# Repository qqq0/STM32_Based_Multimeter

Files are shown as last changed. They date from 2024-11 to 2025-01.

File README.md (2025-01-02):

# **STM32 BLE Multimeter**

**Multimeter features:**
- USB rechargeable LiPo battery  
- BLE control and data streaming  
- Auto range detection  
- Optional OLED display/button control  

**Measurement types:**
- DC voltage: 0 - 60V  
- DC current: 0 - 10A (5 sec)  
- DC power: 0 - 600 W (5 sec)  
- Resistance: 1 - 1M ohm  
- Inductance  
- Capacitance (non-polarized)  
- Diode: 3.3V  

**PCB FRONT:**

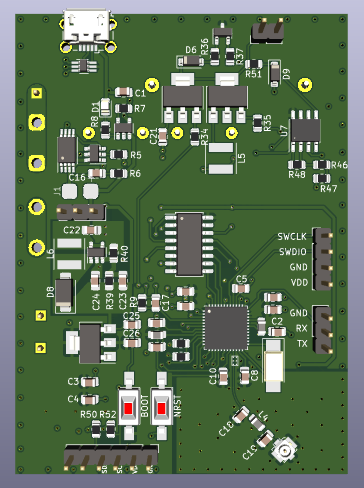
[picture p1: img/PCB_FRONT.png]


**PCB BACK:**

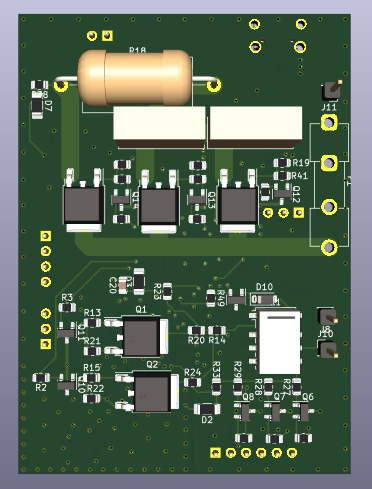
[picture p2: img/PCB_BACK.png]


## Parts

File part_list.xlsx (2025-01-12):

# | Reference | Qty | Value | Shop link | Footprint | order Qty | Price PLN | Total Price | shiping | Kolumna1
1 | C1, C2, C3, C4, C11, C22, C24 | 7 | 4,7 uF | mam 12 https://pl.aliexpress.com/item/1005006285113165.html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 | Capacitor_SMD:C_0805_2012Metric | 1 | 1.69 zł | 6.77 zł | 5.08
2 | C5, C6, C7, C8, C9, C10, C12, C13, C16, C17, C20 | 11 | 100 nF | mam 6 == | Capacitor_SMD:C_0805_2012Metric | 1 | 2.10 zł | 2.10 zł | 0
3 | C18, C19 | 2 | NF |  | Capacitor_SMD:C_0805_2012Metric | 0 |  | 0.00 zł
4 | C21 | 1 | 1uF |  | Capacitor_SMD:C_0805_2012Metric | 0 |  | 0.00 zł
5 | C23 | 1 | 22pF |  | Capacitor_SMD:C_0805_2012Metric_Pad1.18x1.45mm_HandSolder | 0 |  | 0.00 zł
6 | C25, C26 | 2 | 10 uF |  | Capacitor_SMD:C_0805_2012Metric | 0 |  | 0.00 zł
7 | D1 | 1 | LED |  | LED_SMD:LED_0805_2012Metric | 0 |  | 0.00 zł
8 | D2, D3, D7 | 3 | 3V3 D_Zener | https://pl.aliexpress.com/item/1005008305688305.html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 | Resistor_SMD:R_1206_3216Metric_Pad1.30x1.75mm_HandSolder | 1 | 3.79 zł | 8.02 zł | 4.23
9 | D4, D5 | 2 | Z0103MN | https://pl.aliexpress.com/item/1005003648689674.html?pdp_ext_f=%7B"order"%3A"14"%2C"eval"%3A"1"%7D&pdp_npi=4%40dis%21PLN%212.31%212.30%21%21%210.54%210.54%21%402103985c17359917700825783e6386%2112000026643663160%21sea%21PL%212234627410%21X&curPageLogUid=U1r9Vrj7ugJC&utparam-url=scene%3Asearch%7Cquery_from%3A | Package_TO_SOT_SMD:SOT-223 | 1 | 2.39 zł | 7.00 zł | 4.61
10 | D6, D9, D10, D8 | 4 | 1N4148W | - | Diode_SMD:D_SOD-123 | 0 |  | 0.00 zł
11 | F1 | 1 | 10A Fuse | https://pl.aliexpress.com/item/1005003009277399.html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 https://pl.aliexpress.com/item/1005007482886989.html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 | Fuse:Fuseholder_Clip-5x20mm_Eaton_1A5601-01_Inline_P20.80x6.76mm_D1.70mm_Horizontal | 1 | 7.64 zł | 18.64 zł | 11
12 | J1 | 1 | Conn_01x02_Pin | Solder directly to PCB | moje_elementy:batt | 0 |  | 0.00 zł
13 | J2 | 1 | USB_B_Micro | https://pl.aliexpress.com/item/1005006331276552.html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 | Connector_USB:USB_Micro-B_Wuerth_629105150521_CircularHoles | 1 | 1.69 zł | 6.45 zł | 4.76
14 | J3 | 1 | Conn_01x04_Pin |  | Connector_PinHeader_2.54mm:PinHeader_1x04_P2.54mm_Vertical | 0 |  | 0.00 zł
15 | J4 | 1 | Conn_Coaxial | https://pl.aliexpress.com/item/1005005845330862.html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 | Connector_Coaxial:U.FL_Molex_MCRF_73412-0110_Vertical | 1 | 1.99 zł | 7.62 zł | 5.63
16 | J5 | 1 | Conn_01x03_Pin |  | Connector_PinHeader_2.54mm:PinHeader_1x03_P2.54mm_Vertical | 0 |  | 0.00 zł
17 | J7 | 1 | Conn_01x02_Pin |  | Connector_PinHeader_2.54mm:PinHeader_1x02_P2.54mm_Vertical | 0 |  | 0.00 zł
18 | J8, J10, J11 | 3 | Conn_01x01_Pin |  | Connector_PinHeader_2.54mm:PinHeader_1x01_P2.54mm_Vertical | 0 |  | 0.00 zł
19 | J9 | 1 | Conn_01x06_Pin |  | Connector_PinHeader_2.54mm:PinHeader_1x06_P2.54mm_Vertical | 0 |  | 0.00 zł
20 | K1 | 1 | G6K-2 | https://pl.aliexpress.com/item/1005007294651555.html?scm_id=1007.40196.366991.0&scm-url=1007.40196.366991.0 | Relay_SMD:Relay_DPDT_Omron_G6K-2F-Y 3VDC | 1 | 11.13 zł | 17.06 zł | 5.93
21 | L1,L2 | 2 | 10 uH | https://pl.aliexpress.com/item/32955754327.html?pdp_ext_f=%7B"order"%3A"52"%2C"eval"%3A"1"%7D&pdp_npi=4%40dis%21PLN%212.35%212.35%21%21%210.55%210.55%21%40211b81a317359922338361382e774b%2166332555126%21sea%21PL%212234627410%21X&curPageLogUid=cJKDvUjTB2LD&utparam-url=scene%3Asearch%7Cquery_from%3A | Inductor_SMD:L_0805_2012Metric | 1 | 2.35 zł | 7.39 zł | 5.04
22
23 | L4 | 1 | 0H | set | Inductor_SMD:L_0805_2012Metric | 0 |  | 0.00 zł
24 | L5, L6 | 2 | 10uH | https://pl.aliexpress.com/item/1005002090028747.html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 | Inductor_SMD:L_Taiyo-Yuden_NR-50xx | 1 | 2.13 zł | 6.95 zł | 4.82
25 | Q1, Q2, Q3, Q4, Q5 | 5 | AOD2810 | https://pl.aliexpress.com/item/1005005809146268.html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 | moje_elementy:TO-252-1 | 1 | 7.01 zł | 11.04 zł | 4.03
26 | Q6, Q7, Q8, Q9, Q10, Q11, Q12, Q13, Q14, Q15 | 10 | BC327 | Zmienić na PCB coś SOT-23 | Package_TO_SOT_SMD:SOT-23-3 |  |  | 0.00 zł
27 | R2, R3, R4, R30, R31, R32, R34, R35, R37, R43, R45, R49 | 12 | 2k2 R | set | Resistor_SMD:R_0805_2012Metric | 0 |  | 0.00 zł
28 | R5, R8, R13, R15, R28, R41, R42, R44 | 8 | 1k R | set | Resistor_SMD:R_0805_2012Metric | 0 |  | 0.00 zł
29 | R6 | 1 | 100R | set | Resistor_SMD:R_0805_2012Metric | 0 |  | 0.00 zł
30 | R7, R9, R50, R52 | 4 | 2k R | set | Resistor_SMD:R_0805_2012Metric | 0 |  | 0.00 zł
31 | R11, R12 | 2 | 511k R | set | Resistor_SMD:R_0805_2012Metric | 0 |  | 0.00 zł
32 | R14 | 1 | 900k R | set | Resistor_SMD:R_0805_2012Metric | 0 |  | 0.00 zł
33 | R16 | 1 | 0,01 R | https://pl.aliexpress.com/item/1005005181109774.html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 | Resistor_THT:R_Box_L14.0mm_W5.0mm_P9.00mm | 1 | 1.99 zł | 6.81 zł | 4.82
34 | R17 | 1 | 0,1 R | https://pl.aliexpress.com/item/1005005181109774.html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 | Resistor_THT:R_Box_L14.0mm_W5.0mm_P9.00mm | 1 | 1.99 zł | 1.99 zł
35 | R18 | 1 | 1 R |  | Resistor_THT:R_Axial_DIN0918_L18.0mm_D9.0mm_P25.40mm_Horizontal | 0 |  | 0.00 zł
36 | R19, R20, R21, R22, R23, R25, R26, R29, R33, R38, R51 | 11 | 100k R | https://pl.aliexpress.com/item/1005007636030489.html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 | Resistor_SMD:R_0805_2012Metric | 1 | 13.19 zł | 13.19 zł |  | 80value 2000 pcs
37 | R24 | 1 | 9,1k R | set | Resistor_SMD:R_0805_2012Metric | 0 |  | 0.00 zł
38 | R27 | 1 | 100 R | set | Resistor_SMD:R_0805_2012Metric | 0 |  | 0.00 zł
39 | R36 | 1 | 220 R | set | Resistor_SMD:R_0805_2012Metric | 0 |  | 0.00 zł
40 | R39 | 1 | 470k R | set | Resistor_SMD:R_0805_2012Metric_Pad1.20x1.40mm_HandSolder | 0 |  | 0.00 zł
41 | R40 | 1 | 75k R | set | Resistor_SMD:R_0805_2012Metric_Pad1.20x1.40mm_HandSolder | 0 |  | 0.00 zł
42 | R46 | 1 | 43k R | set | Resistor_SMD:R_0805_2012Metric | 0 |  | 0.00 zł
43 | R47 | 1 | 330 R | set | Resistor_SMD:R_0805_2012Metric | 0 |  | 0.00 zł
44 | R48 | 1 | 390k R | set | Resistor_SMD:R_0805_2012Metric | 0 |  | 0.00 zł
45 | SW1 | 1 | NRST |  | Button_Switch_SMD:SW_SPST_FSMSM | 0 |  | 0.00 zł
46 | SW3 | 1 | BOOT |  | Button_Switch_SMD:SW_SPST_FSMSM | 0 |  | 0.00 zł
47 | SW4 | 1 | SW_DPDT_x2 |  | Connector_PinHeader_2.54mm:PinHeader_1x03_P2.54mm_Vertical | 0 |  | 0.00 zł
48 | U1 | 1 | STM32WB55CGUx | https://pl.aliexpress.com/item/1005008038998896.html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 | Package_DFN_QFN:QFN-48-1EP_7x7mm_P0.5mm_EP5.6x5.6mm | 2 | 13.59 zł | 31.71 zł | 4.53
49 | U3 | 1 | LTC4054XES5-4.2 | https://pl.aliexpress.com/item/1005006928245080.html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 | Package_TO_SOT_SMD:TSOT-23-5 | 1 | 2.17 zł | 6.74 zł | 4.57
50 | U4 | 1 | DW01A | https://pl.aliexpress.com/item/1005007467171055.html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 | Package_TO_SOT_SMD:SOT-23-6 | 1 | 4.79 zł | 9.32 zł | 4.53
51 | U5 | 1 | FS8205A | set | Package_SO:TSSOP-8_4.4x3mm_P0.65mm | 0 |  | 0.00 zł
52 | U6 | 1 | ~ | https://pl.aliexpress.com/item/1005007978414767.html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 | Package_TO_SOT_SMD:SOT-363_SC-70-6_Handsoldering | 1 | 2.25 zł | 6.32 zł | 4.07
53 | U7 | 1 | MCP602 | https://pl.aliexpress.com/item/1005006922903852.html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 | Package_SO:SOP-8_3.9x4.9mm_P1.27mm | 1 | 4.20 zł | 4.20 zł | 0
54 | U8 | 1 | ~ | https://pl.aliexpress.com/item/1005006779802761.html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 | moje_elementy:MLPF-WB55 | 2 | 4.69 zł | 13.08 zł | 3.7
55 | U9 | 1 | TPS61040DBV |  | Package_TO_SOT_SMD:SOT-23-5 | 0 |  | 0.00 zł
56 | U10 | 1 | AMS1117-3.3 |  | Package_TO_SOT_SMD:SOT-223-3_TabPin2 | 0 |  | 0.00 zł
57 | U11 | 1 | 4051 | https://pl.aliexpress.com/item/1005007329677951.html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 | Package_SO:SOP-16_4.4x10.4mm_P1.27mm | 1 | 3.20 zł | 6.79 zł | 3.59
58 | Y1 | 1 | Crystal 32 MHz | https://pl.aliexpress.com/item/1005006142975427.html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 | Crystal:Crystal_SMD_5032-2Pin_5.0x3.2mm_HandSoldering | 1 | 4.20 zł | 4.20 zł
59 |  | 1 | Antena | https://pl.aliexpress.com/item/1005006057629673.html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 | 2.4G Bluetooth wifi mała antena 5G 5.8G UFL | 1 | 6.69 zł | 6.69 zł | 0
60 |  |  |  |  |  |  |  | 0.00 zł
61 |  |  |  |  |  |  |  | 0.00 zł
 |  |  |  |  |  | suma | 210.08 zł

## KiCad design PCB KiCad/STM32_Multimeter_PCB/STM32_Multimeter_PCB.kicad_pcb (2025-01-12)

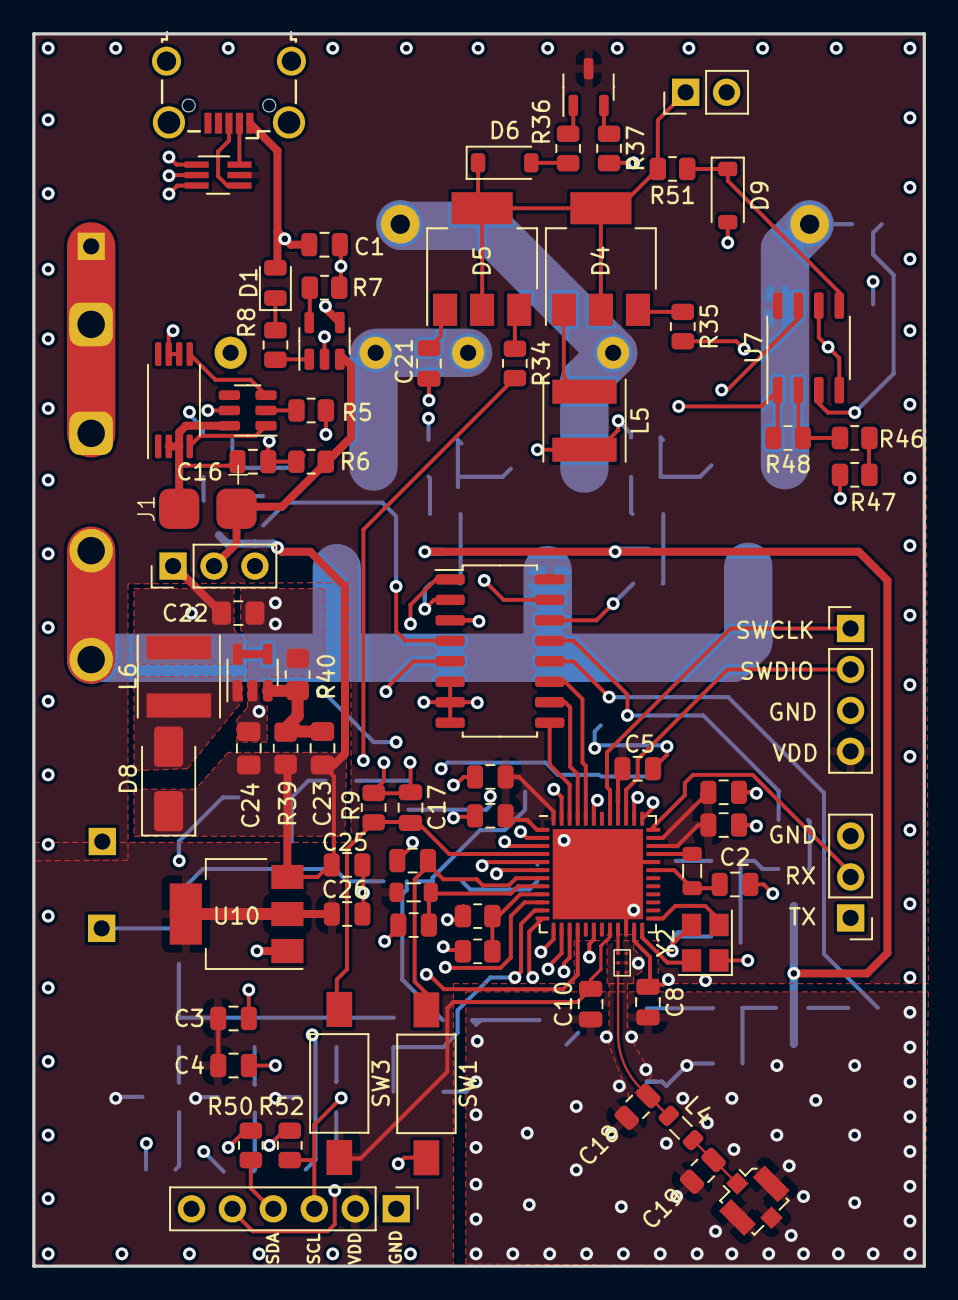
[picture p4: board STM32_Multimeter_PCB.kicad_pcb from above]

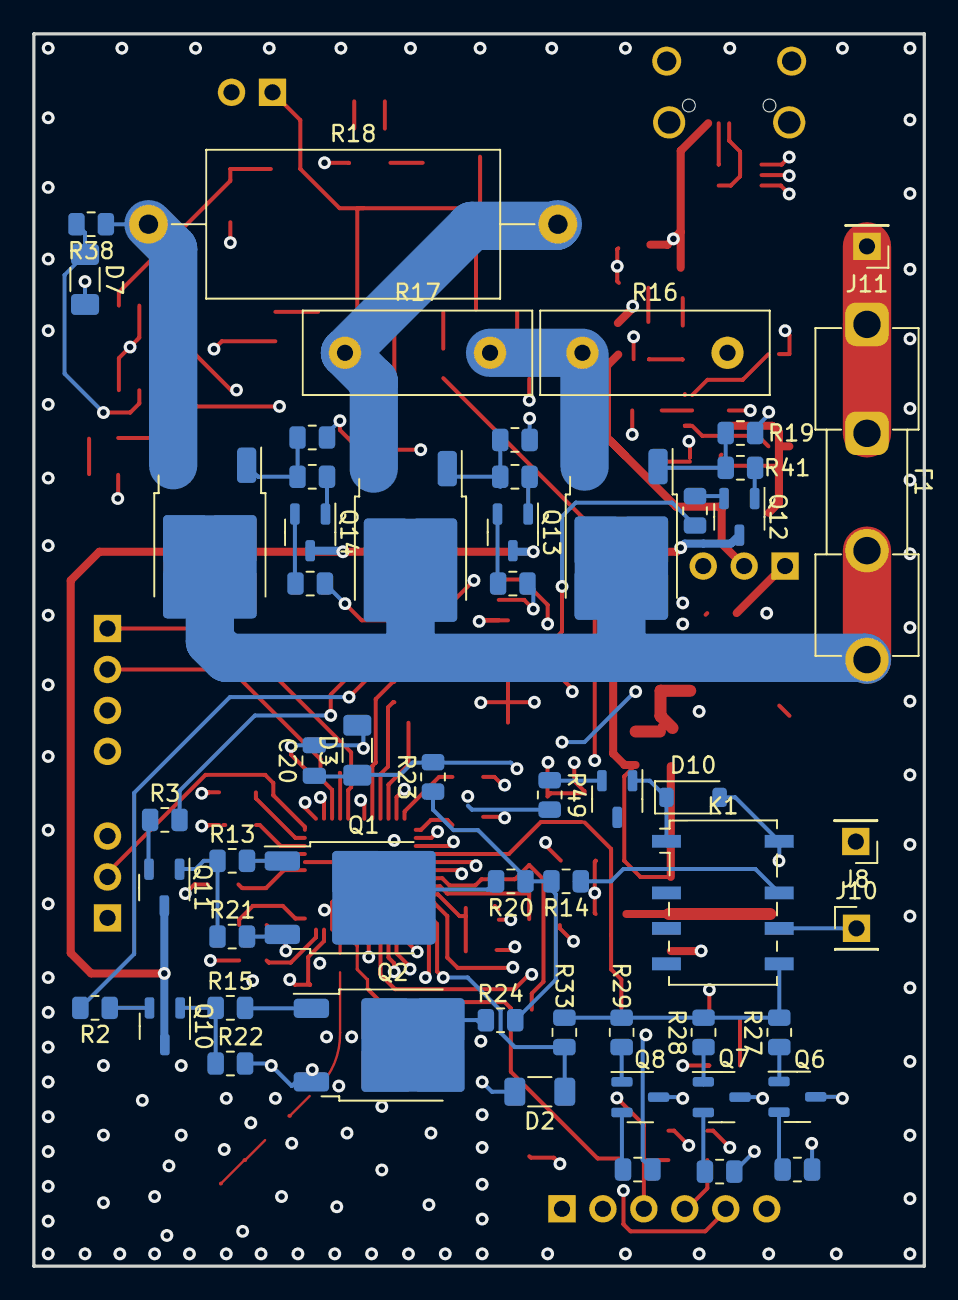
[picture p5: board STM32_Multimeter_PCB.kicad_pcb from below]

Board: 4 copper layers, 55.2 x 76.5 mm, 130 parts (55 on the bottom side), 105 nets.

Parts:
C1, C2, C3, C4, C11: 4,7 uF; C_0805_2012Metric
C5, C6, C7, C8, C9, C10, C12, C13, C16, C17, C20: 100 nF; C_0805_2012Metric
C18, C19: NF; C_0805_2012Metric
C21: 1uF; C_0805_2012Metric
C22, C24: 4.7uF; C_0805_2012Metric_Pad1.18x1.45mm_HandSolder
C23: 22pF; C_0805_2012Metric_Pad1.18x1.45mm_HandSolder
C25, C26: 10 uF; C_0805_2012Metric
D1: LED; LED_0805_2012Metric
D2, D3, D7: 3V3 D_Zener; R_1206_3216Metric_Pad1.30x1.75mm_HandSolder
D4, D5: Z0103MN; SOT-223
D6, D9, D10: 1N4148W; D_SOD-123
D8: 1N4001; D_SMA
F1: 10A Fuse; Fuseholder_Clip-5x20mm_Eaton_1A5601-01_Inline_P20.80x6.76mm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
J1: Conn_01x02_Pin; batt
J2: USB_B_Micro; USB_Micro-B_Wuerth_629105150521_CircularHoles
J3: Conn_01x04_Pin; PinHeader_1x04_P2.54mm_Vertical
J4: Conn_Coaxial; U.FL_Molex_MCRF_73412-0110_Vertical
J5: Conn_01x03_Pin; PinHeader_1x03_P2.54mm_Vertical
J7: Conn_01x02_Pin; PinHeader_1x02_P2.54mm_Vertical
J8, J10, J11: Conn_01x01_Pin; PinHeader_1x01_P2.54mm_Vertical
J9: Conn_01x06_Pin; PinHeader_1x06_P2.54mm_Vertical
K1: G6K-2; Relay_DPDT_Omron_G6K-2F-Y
L1, L2: 10 uH; L_0805_2012Metric
L4: 0H; L_0805_2012Metric
L5, L6: 10uH; L_Taiyo-Yuden_NR-50xx
Q1, Q2, Q3, Q4, Q5: AOD2810; TO-252-1
Q6, Q7, Q8, Q9, Q10, Q11, Q12, Q13, Q14, Q15: BC327; SOT-23-3
R2, R3, R4, R30, R31, R32, R34, R35, R37, R43, R45, R49: 2k2 R; R_0805_2012Metric
R5, R8, R13, R15, R28, R41, R42, R44: 1k R; R_0805_2012Metric
R6: 100R; R_0805_2012Metric
R7, R9, R50, R52: 2k R; R_0805_2012Metric
R11, R12: 511k R; R_0805_2012Metric
R14: 910k R; R_0805_2012Metric
R16: 0,01 R; R_Box_L14.0mm_W5.0mm_P9.00mm
R17: 0,1 R; R_Box_L14.0mm_W5.0mm_P9.00mm
R18: 1 R; R_Axial_DIN0918_L18.0mm_D9.0mm_P25.40mm_Horizontal
R19, R20, R21, R22, R23, R25, R26, R29, R33, R38, R51: 100k R; R_0805_2012Metric
R24: 9,1k R; R_0805_2012Metric
R27: 100 R; R_0805_2012Metric
R36: 220 R; R_0805_2012Metric
R39: 470k R; R_0805_2012Metric_Pad1.20x1.40mm_HandSolder
R40: 75k R; R_0805_2012Metric_Pad1.20x1.40mm_HandSolder
R46: 43k R; R_0805_2012Metric
R47: 330 R; R_0805_2012Metric
R48: 390k R; R_0805_2012Metric
SW1: NRST; SW_SPST_FSMSM
SW3: BOOT; SW_SPST_FSMSM
SW4: SW_DPDT_x2; PinHeader_1x03_P2.54mm_Vertical
U1: STM32WB55CGUx; QFN-48-1EP_7x7mm_P0.5mm_EP5.6x5.6mm
U3: LTC4054XES5-4.2; TSOT-23-5
U4: DW01A; SOT-23-6
U5: FS8205A; TSSOP-8_4.4x3mm_P0.65mm
U6: SOT-363_SC-70-6_Handsoldering
U7: SOP-8_3.9x4.9mm_P1.27mm
U8: MLPF-WB55
U9: TPS61040DBV; SOT-23-5
U10: AMS1117-3.3; SOT-223-3_TabPin2
U11: 4051; SOP-16_4.4x10.4mm_P1.27mm
Y2: Crystal_GND24; Crystal_SMD_3225-4Pin_3.2x2.5mm

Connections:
+5V: C1.2, D1.2 (A), J2.1 (VBUS), U3.4 (V_{CC})
+9V: C23.1, C24.1, C25.2, D8.1 (K), Q10.3 (E), Q11.3 (E), Q12.3 (E), Q13.3 (E), Q14.3 (E), R39.1, U10.3 (VI)
+BATT: C22.1, L6.1, R11.2, SW4.1 (A), U9.4 (EN), U9.5 (VIN)
A: U1.44 (PB4), U11.11 (A)
B: U1.45 (PB5), U11.10 (B)
BATT sens: R11.1, R12.2, U1.9 (PA0)
BU1: J9.6, U1.2 (PC14)
BU2: J9.5, U1.3 (PC15)
C: U1.46 (PB6), U11.9 (C)
C on: R34.2, U1.16 (PA7)
CL input: U1.14 (PA5), U7.7 (Voutb)
GND: C1.1, C2.2, C3.1, C4.1, C5.1, C6.1, C7.1, C8.2, C9.2, C10.1, C11.1, C12.1, C13.1, C17.1, C18.2, C19.2, C20.2, C21.2, C22.2, C24.2, C25.1, C26.1, D2.2 (A), D3.2 (A), D7.2 (A), D9.2 (A), D10.2 (A), J2.5 (GND), J2.6 (Shield), J3.3, J4.2 (Ext), J5.3, J7.2, J8.1, J9.1, K1.8, L5.2, Q1.3 (S), Q2.3 (S), R5.1, R7.1, R9.1, R12.1, R16.2, R19.2, R21.2, R22.2, R25.2, R26.2, R40.2, R46.1, R50.1, R52.1, SW1.2, U1.22 (VSSRF), U1.32 (VSSSMPS), U1.49 (VSS), U3.2 (GND), U5.6 (S2), U5.7 (S2), U6.2 (GND), U7.4 (Vss), U7.6 (Vinb-), U8.2 (GND_4), U8.4 (GND_3), U8.5 (GND_2), U8.6 (GND_1), U9.2 (GND), U10.1 (GND), U11.6 (Inh), U11.7 (VEE), U11.8 (VSS), Y2.1, Y2.3
L on: R35.2, U1.15 (PA6)
unnamed: D1.1 (K), R8.2
unnamed: D4.1 (A1), L5.1
unnamed: D4.2 (A2), D4.4 (A4), D5.2 (A2), D5.4 (A4), D6.1 (K), J7.1, R51.2
unnamed: D4.3 (G), R35.1
unnamed: C21.1, D5.1 (A1)
unnamed: D5.3 (G), R34.1
unnamed: D6.2 (A), R36.1
unnamed: D7.1 (K), R38.2, U7.3 (Vina+)
unnamed: D8.2 (A), L6.2, U9.1 (SW)
unnamed: D9.1 (K), R51.1, U7.5 (Vinb+)
unnamed: D10.1 (K), K1.1, Q15.1 (C)
unnamed: C16.1, J1.1, U4.6 (GND), U5.2 (S1), U5.3 (S1)
unnamed: J1.2, R6.2, SW4.2 (B), U3.3 (BAT)
unnamed: J2.3 (D+), U6.4 (D4)
unnamed: J2.2 (D-), U6.6 (D3)
unnamed: J3.1, U1.41 (PA14)
unnamed: J3.2, U1.39 (PA13)
unnamed: C19.1, J4.1 (In), L4.2
unnamed: J5.1, U1.18 (PA9)
unnamed: J5.2, U1.36 (PA10)
unnamed: J9.3, R52.2, U1.5 (PB8)
unnamed: J9.4, R50.2, U1.6 (PB9)
unnamed: J10.1, K1.6
unnamed: F1.1, J11.1
unnamed: K1.5, R27.2, R28.2, R29.2, R33.1
unnamed: K1.7, R14.1
unnamed: Q1.1 (D), R20.2
unnamed: Q1.2 (G), R13.2
unnamed: Q2.1 (D), R24.1
unnamed: Q2.2 (G), R15.2
unnamed: F1.2, Q3.1 (D), Q4.1 (D), Q5.1 (D)
unnamed: Q3.2 (G), R19.1, R41.1
unnamed: Q3.3 (S), R16.1, R17.2
unnamed: Q4.2 (G), R25.1, R42.1
unnamed: Q4.3 (S), R17.1, R18.2
unnamed: Q5.2 (G), R26.1, R44.1
unnamed: Q5.3 (S), R18.1, R38.1
unnamed: Q6.2 (B), R30.2
unnamed: Q6.1 (C), R27.1
unnamed: Q7.2 (B), R31.2
unnamed: Q7.1 (C), R28.1
unnamed: Q8.2 (B), R32.2
unnamed: Q8.1 (C), R29.1
unnamed: Q9.2 (B), R37.1
unnamed: Q9.1 (C), R36.2
unnamed: Q10.2 (B), R2.1
unnamed: Q10.1 (C), R15.1, R22.1
unnamed: Q11.2 (B), R3.1
unnamed: Q11.1 (C), R13.1, R21.1
unnamed: Q12.2 (B), R4.1
unnamed: Q12.1 (C), R41.2
unnamed: Q13.2 (B), R43.1
unnamed: Q13.1 (C), R42.2
unnamed: Q14.2 (B), R45.1
unnamed: Q14.1 (C), R44.2
unnamed: Q15.2 (B), R49.1
unnamed: R14.2, R20.1, R23.1, R24.2
unnamed: R46.2, R47.1
unnamed: C12.2, SW1.1, U1.7 (NRST)
unnamed: U1.25 (OSC_IN), Y2.2
unnamed: U1.24 (OSC_OUT), Y2.4
unnamed: U1.37 (PA11), U6.3 (D2)
unnamed: U1.38 (PA12), U6.1 (D1)
unnamed: U1.47 (PB7), U11.3 (X)
unnamed: C17.2, R9.2, SW3.1, U1.4 (PH3)
unnamed: U1.21 (RF1), U8.3 (IN)
unnamed: C11.2, L2.1, U1.8 (VDDA)
unnamed: C2.1, L1.2, U1.31 (VFBSMPS)
unnamed: L1.1, U1.33 (VLXSMPS)
unnamed: R7.2, U3.5 (PROG)
unnamed: R8.1, U3.1 (~CHRG)
unnamed: R5.2, U4.2 (CS)
unnamed: U4.3 (OC), U5.5 (G2)
unnamed: U4.1 (OD), U5.4 (G1)
unnamed: C16.2, R6.1, U4.5 (VCC)
unnamed: R47.2, R48.1, U7.2 (Vina-)
unnamed: C18.1, L4.1, U8.1 (OUT)
unnamed: C23.2, R39.2, R40.1, U9.3 (FB)
R input: D2.1 (K), R33.2, U1.11 (PA2)
Range 0,1A: R45.2, U11.14 (X1)
Range 1 to 100 ohm: R30.1, U11.15 (X2)
Range 1A: R43.2, U11.2 (X6)
Range 1/10: R3.2, U11.13 (X0)
Range 1/100: R2.2, U11.12 (X3)
Range 10A: R4.2, U11.4 (X7)
Range 10k to 1kk ohm: R32.1, U11.1 (X4)
Range 100 to 10k ohm: R31.1, U11.5 (X5)
Resistance rel: R49.2, U1.43 (PB3)
VDD: C3.2, C4.2, C5.2, C6.2, C7.2, C8.1, C9.1, C10.2, C13.2, C26.2, J3.4, J9.2, L2.2, Q6.3 (E), Q7.3 (E), Q8.3 (E), Q9.3 (E), SW3.2, U1.1 (VBAT), U1.20 (VDD), U1.23 (VDDRF), U1.34 (VDDSMPS), U1.35 (VDD), U1.40 (VDDUSB), U1.48 (VDD), U6.5 (VCC), U7.8 (Vdd), U10.2 (VO), U11.16 (VDD)
charge LC: R37.2, U1.13 (PA4)
current input: R48.2, U1.12 (PA3), U7.1 (Vouta)
voltage input: C20.1, D3.1 (K), R23.2, U1.10 (PA1)

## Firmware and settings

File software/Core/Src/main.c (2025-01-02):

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
/* Includes ------------------------------------------------------------------*/
#include "main.h"
#include "usb_device.h"

/* USER CODE BEGIN Includes */
#include "stdbool.h"
#include "usbd_cdc_if.h"
#include "stdio.h"
/* USER CODE END Includes */

/* USER CODE BEGIN PTD */
//Multiplexer settings
#define voltage 0x09
#define voltage_1_10 0x00
#define voltage_1_100 0x03
#define current_0_1A 0x01
#define current_1A 0x06
#define curremt_10A 0x07
#define resistance_100 0x02
#define resistance_1k	0x05
#define resistance_100k 0x04

typedef enum {
	IDLE,
	VOLTAGE,
	RESISTANECE,
	CURRENT,
	CONTINUITY,
	POWER,
	INDUCTANCE,
	CAPACITANCE,
	STATE_COUNT
}State_t;
/* USER CODE END PTD */

ADC_HandleTypeDef hadc1;

I2C_HandleTypeDef hi2c1;

IPCC_HandleTypeDef hipcc;

RTC_HandleTypeDef hrtc;

TIM_HandleTypeDef htim2;

UART_HandleTypeDef huart1;

void SystemClock_Config(void);
void PeriphCommonClock_Config(void);
static void MX_GPIO_Init(void);
static void MX_ADC1_Init(void);
static void MX_USART1_UART_Init(void);
static void MX_IPCC_Init(void);
static void MX_RTC_Init(void);
static void MX_I2C1_Init(void);
static void MX_TIM2_Init(void);
static void MX_RF_Init(void);
/* USER CODE BEGIN PFP */
void setMux(int val){

	if(val<=0x07){								// if value is out of range set input X to 0
		HAL_GPIO_WritePin(GPIOB, GPIO_PIN_7, 1);
	}else{
		HAL_GPIO_WritePin(GPIOB, GPIO_PIN_7, 0);
	}

	HAL_GPIO_WritePin(GPIOB, GPIO_PIN_4, (val & 0x01) ? 1 : 0);	//val sets A B C inputs, for example val = 3 -> 0b011 -> A = 0 B = 1 C = 1
	HAL_GPIO_WritePin(GPIOB, GPIO_PIN_5, (val & 0x02) ? 1 : 0);
	HAL_GPIO_WritePin(GPIOB, GPIO_PIN_6, (val & 0x04) ? 1 : 0);
}

void ADC_SetActiveChannel(ADC_HandleTypeDef *hadc, uint32_t AdcChannel)
{
  ADC_ChannelConfTypeDef sConfig = {0};
  sConfig.Channel = AdcChannel;
  sConfig.Rank = 1;
  sConfig.SamplingTime = ADC_SAMPLETIME_6CYCLES_5;
  if (HAL_ADC_ConfigChannel(hadc, &sConfig) != HAL_OK)
  {
   Error_Handler();
  }
}

float getVoltge(){

	uint32_t raw_v;

	HAL_GPIO_WritePin(GPIOB, GPIO_PIN_3, 0);		//set relay to voltage AFE
	setMux(voltage_1_100);
	HAL_Delay(100);

	ADC_SetActiveChannel(&hadc1, ADC_CHANNEL_6);	//set adc channel to voltage input
	HAL_ADC_Start(&hadc1);

	HAL_ADC_PollForConversion(&hadc1, 100);
	raw_v = 100*HAL_ADC_GetValue(&hadc1);

	if(raw_v<4000){
		setMux(voltage_1_10);
		HAL_ADC_Start(&hadc1);
		HAL_ADC_PollForConversion(&hadc1, 100);
		raw_v = 10*HAL_ADC_GetValue(&hadc1);
	}

	if(raw_v<4000){
		setMux(voltage);
		HAL_ADC_PollForConversion(&hadc1, 100);
		raw_v = HAL_ADC_GetValue(&hadc1);
	}

	float V = (raw_v/4095.0f)*3.3f;
	return V;
}

float getResistance(){
	float R;
	int adc;
	HAL_GPIO_WritePin(GPIOB, GPIO_PIN_3, 1);		//set relay to resistance AFE
	setMux(resistance_100k);
	HAL_Delay(100);

	ADC_SetActiveChannel(&hadc1, ADC_CHANNEL_7);	//set adc channel to resistance input
	HAL_ADC_Start(&hadc1);
	HAL_ADC_PollForConversion(&hadc1, 100);

	adc = HAL_ADC_GetValue(&hadc1);
	R = (100000*adc/4095.0f)/(1-adc/4095.0f);

	if(R<10000){
		setMux(resistance_1k);
		HAL_ADC_Start(&hadc1);
		HAL_ADC_PollForConversion(&hadc1, 100);
		adc = HAL_ADC_GetValue(&hadc1);
		R = (1000*adc/4095.0f)/(1-adc/4095.0f);
	}
	if(R<1000){
		setMux(resistance_100);
		HAL_ADC_Start(&hadc1);
		HAL_ADC_PollForConversion(&hadc1, 100);
		adc = HAL_ADC_GetValue(&hadc1);
		R = (100*adc/4095.0f)/(1-adc/4095.0f);
	}
	return R;
}

float getCurrent(){		// disconects breafly when swiching range because multiplexer can operate one output at the time - to fix it you need to swich one range off after siching on different one first
	float I;
	int adc;
	setMux(curremt_10A);
	HAL_Delay(10);

	ADC_SetActiveChannel(&hadc1, ADC_CHANNEL_8);	//set adc channel to current input
	HAL_ADC_Start(&hadc1);
	HAL_ADC_PollForConversion(&hadc1, 100);

	adc = HAL_ADC_GetValue(&hadc1);
	I = (adc/4095.0f)*3.3f*10;	// V/R resistance is 1/100 ohm with 10x amplifier -> V/10*1/100 -> V*10

	if(I<1){
		setMux(current_1A);
		HAL_Delay(10);
		HAL_ADC_Start(&hadc1);
		HAL_ADC_PollForConversion(&hadc1, 100);
		adc = HAL_ADC_GetValue(&hadc1);
		I = (adc/4095.0f)*3.3f*1;	// V/R resistance is 1/10 ohm with 10x amplifier -> V/10*1/10 -> V*1
	}

	if(I<0.1f){
			setMux(current_0_1A);
			HAL_Delay(10);
			HAL_ADC_Start(&hadc1);
			HAL_ADC_PollForConversion(&hadc1, 100);
			adc = HAL_ADC_GetValue(&hadc1);
			I = (adc/4095.0f)*3.3f*0.1f;	// V/R resistance is 1 ohm with 10x amplifier -> V/10*1 -> V*0.1
		}
	return I;
}




/* USER CODE END PFP */

/* USER CODE BEGIN 0 */
volatile float frequency = 0;
volatile uint32_t capture_current = 0;
volatile uint32_t capture_previous = 0;
volatile uint32_t time_diff_us = 0;
volatile bool first_captured = 0;

void HAL_TIM_IC_CaptureCallback(TIM_HandleTypeDef *htim){
	if(htim->Instance == TIM2){
		if(htim->Channel == HAL_TIM_ACTIVE_CHANNEL_1){


			capture_current = HAL_TIM_ReadCapturedValue(htim, TIM_CHANNEL_1);

			if(first_captured){

				if(capture_current >= capture_previous){
					time_diff_us = capture_current - capture_previous;
				}else{
					time_diff_us = (0xFFFF - capture_previous) + capture_current + 1;
				}

				frequency = time_diff_us == 0 ? 0xFFFF : 1000000.0f/time_diff_us;  //10^6 to get frequency in Hz

			}else{
				first_captured = 1;
			}

			capture_previous = capture_current;

		}
	}
}

const float pi = 3.1416;
const float ref_C = 0.000001;
const float ref_L = 0.000001;

float getInductance(){
	float L;

	HAL_GPIO_WritePin(GPIOA, GPIO_PIN_7, 1);

	HAL_GPIO_WritePin(GPIOA, GPIO_PIN_4, 1); // charge
	HAL_Delay(10);
	HAL_GPIO_WritePin(GPIOA, GPIO_PIN_4, 0);
	HAL_Delay(100);							//time for LC oscillation and frequency capture

	HAL_GPIO_WritePin(GPIOA, GPIO_PIN_7, 0);

	L=1000000/((2*pi*frequency)*(2*pi*frequency)*ref_C);	// result in uH

	return L;
}
float getCapacitance(){
	float C;

	HAL_GPIO_WritePin(GPIOA, GPIO_PIN_6, 1);

	HAL_GPIO_WritePin(GPIOA, GPIO_PIN_4, 1); // charge
	HAL_Delay(10);
	HAL_GPIO_WritePin(GPIOA, GPIO_PIN_4, 0);
	HAL_Delay(100);							//time for LC oscillation and frequency capture

	HAL_GPIO_WritePin(GPIOA, GPIO_PIN_6, 0);

	C=1000000/((2*pi*frequency)*(2*pi*frequency)*ref_L);	// result in uF

	return C;
}



void sendDataBle(uint8_t* data, uint16_t length){
//	tBleStatus status;

//	status = Custom_STM_App_Update_Char(CUSTOM_STM_CHARWRITE, data);

}

State_t state = IDLE;
/* USER CODE END 0 */

/**
  * @brief  The application entry point.
  * @retval int
  */
int main(void)
{

  /* MCU Configuration--------------------------------------------------------*/

  /* Reset of all peripherals, Initializes the Flash interface and the Systick. */
  HAL_Init();
  /* Config code for STM32_WPAN (HSE Tuning must be done before system clock configuration) */
  MX_APPE_Config();

  /* Configure the system clock */
  SystemClock_Config();

  /* Configure the peripherals common clocks */
  PeriphCommonClock_Config();

  /* IPCC initialisation */
  MX_IPCC_Init();

  /* Initialize all configured peripherals */
  MX_GPIO_Init();
  MX_ADC1_Init();
  MX_USART1_UART_Init();
  MX_USB_Device_Init();
  MX_RTC_Init();
  MX_I2C1_Init();
  MX_TIM2_Init();
  MX_RF_Init();
  /* USER CODE BEGIN 2 */
  HAL_ADC_Start(&hadc1);
  HAL_TIM_IC_Start(&htim2, TIM_CHANNEL_1);



  uint8_t msg[50] = "test\n\r";

  float measurement;

  /* USER CODE END 2 */

  /* Init code for STM32_WPAN */
  MX_APPE_Init();

  /* Infinite loop */
  /* USER CODE BEGIN WHILE */
  while (1)
  {
	  switch (state) {
	  	  case IDLE:
	  		  // Switch off all outputs:
	  		  HAL_GPIO_WritePin(GPIOA, GPIO_PIN_4, 0);
	  		  HAL_GPIO_WritePin(GPIOA, GPIO_PIN_6, 0);
	  		  HAL_GPIO_WritePin(GPIOA, GPIO_PIN_7, 0);
	  		  HAL_GPIO_WritePin(GPIOB, GPIO_PIN_3, 0);
	  		  HAL_GPIO_WritePin(GPIOB, GPIO_PIN_4, 0);
	  		  HAL_GPIO_WritePin(GPIOB, GPIO_PIN_5, 0);
	  		  HAL_GPIO_WritePin(GPIOB, GPIO_PIN_6, 0);
	  		  HAL_GPIO_WritePin(GPIOB, GPIO_PIN_7, 0);
	  		  HAL_Delay(250);

	  	  case VOLTAGE:
	  		  measurement = getVoltge();
	  		  sprintf(msg,"V: %f /r/n",measurement);

	  	  case RESISTANECE:
	  		  measurement = getResistance();
	  		  sprintf(msg,"R: %f /r/n",measurement);

	  	  case CURRENT:
	  		  measurement = getCurrent();
	  		  sprintf(msg,"I: %f /r/n",measurement);

	  	  case CONTINUITY:
	  		  measurement = getResistance();
	  		  if(measurement<100){		// continuity is detected if connection has low resistance
	  			  measurement = 1;
	  		  }else{
	  			  measurement = 0;
	  		  }
	  		sprintf(msg,"CON: %d /r/n",(int)measurement);

	  	  case POWER:
	  		measurement = getVoltge();
	  		measurement = measurement*getCurrent();
	  		sprintf(msg,"P: %f /r/n");

	  	  case INDUCTANCE:
	  		  measurement = getInductance();
	  		  sprintf(msg,"L: %f uH/r/n");

	  	  case CAPACITANCE:
	  		  measurement = getCapacitance();
	  		  sprintf(msg,"C: %f uH/r/n");

	  	  default:
	  		  state = IDLE;
	  }


	  CDC_Transmit_FS(msg, sizeof(msg));
	  HAL_Delay(250);
    /* USER CODE END WHILE */
    MX_APPE_Process();

    /* USER CODE BEGIN 3 */
  }
  /* USER CODE END 3 */
}

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
/* USER CODE BEGIN 4 */

void HAL_GPIO_EXTI_Callback(uint16_t GPIO_Pin){		// interrupt triggered on rising edge
		if(GPIO_Pin == GPIO_PIN_14){	// pin with internal pulldown
			state++;
			if(state >= STATE_COUNT){
				state = IDLE;
			}
		}
		if(GPIO_Pin == GPIO_PIN_15){	// pin with internal pulldown
			if(state == IDLE){
				state = STATE_COUNT-1;
			}else{
				state--;
			}
		}
}

/* USER CODE END 4 */
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


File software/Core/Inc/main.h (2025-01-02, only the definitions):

#define BU1_Pin GPIO_PIN_14
#define BU1_GPIO_Port GPIOC
#define BU1_EXTI_IRQn EXTI15_10_IRQn
#define BU2_Pin GPIO_PIN_15
#define BU2_GPIO_Port GPIOC
#define BU2_EXTI_IRQn EXTI15_10_IRQn
#define BATT_sens_Pin GPIO_PIN_0
#define BATT_sens_GPIO_Port GPIOA
#define V_Pin GPIO_PIN_1
#define V_GPIO_Port GPIOA
#define R_Pin GPIO_PIN_2
#define R_GPIO_Port GPIOA
#define I_Pin GPIO_PIN_3
#define I_GPIO_Port GPIOA
#define charge_LC_Pin GPIO_PIN_4
#define charge_LC_GPIO_Port GPIOA
#define L_on_Pin GPIO_PIN_6
#define L_on_GPIO_Port GPIOA
#define C_on_Pin GPIO_PIN_7
#define C_on_GPIO_Port GPIOA
#define Relay_Pin GPIO_PIN_3
#define Relay_GPIO_Port GPIOB
#define A_Pin GPIO_PIN_4
#define A_GPIO_Port GPIOB
#define B_Pin GPIO_PIN_5
#define B_GPIO_Port GPIOB
#define C_Pin GPIO_PIN_6
#define C_GPIO_Port GPIOB
#define X_Pin GPIO_PIN_7
#define X_GPIO_Port GPIOB

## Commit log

2024-11-14 Created KiCAD project
    [STM32_Multimeter_PCB.kicad_pcb, STM32_Multimeter_PCB.kicad_sch]
2024-11-15 Added stm32 to PCB with components nesesery for runing it
    [STM32_Multimeter_PCB.kicad_sch]
2024-11-15 Added battery charger/protection, 3,3v buck/boost regualtor andUSB connector
    [STM32_Multimeter_PCB.kicad_sch]
2024-11-16 Added mcu connectivity: SWD, USB, UART and BLE with supporting circuitry
    [STM32_Multimeter_PCB.kicad_sch]
2024-11-17 Added voltage and current sensing input
    [STM32_Multimeter_PCB.kicad_sch, untitled.kicad_sch]
2024-11-19 Added resistance measurement circuitry
    [untitled.kicad_sch]
2024-11-25 Changed RF filter
    [STM32_Multimeter_PCB.kicad_sch, untitled.kicad_sch]
2024-11-27 Added LC osicilator for inductance and capacitance measurment
    [untitled.kicad_sch]
2024-11-29 Added 9V SMPS, swiched 3,3V SMPS to linnear regulator
    [STM32_Multimeter_PCB.kicad_sch, untitled.kicad_sch]
2024-11-29 Added BJT for swiching range mosfets from 9V
    [untitled.kicad_sch]
2024-11-29 Added shunt voltage amplifier
    [untitled.kicad_sch]
2024-12-03 added resistance/voltage measurment relay
    [untitled.kicad_sch]
2024-12-03 Added component footprints
    [STM32_Multimeter_PCB.kicad_sch, untitled.kicad_sch]
2024-12-04 Connected measuring circuitry to STM32
    [STM32_Multimeter_PCB.kicad_sch, untitled.kicad_sch]
2024-12-08 Created pcb schematic
    [STM32_Multimeter_PCB.kicad_pcb, STM32_Multimeter_PCB.kicad_sch, untitled.kicad_sch]
2024-12-22 Routed Analog and Microcontroler section
    [STM32_Multimeter_PCB.kicad_pcb, STM32_Multimeter_PCB.kicad_sch]
2024-12-23 routed out signals and power planes
    [STM32_Multimeter_PCB.kicad_pcb, STM32_Multimeter_PCB.kicad_sch, untitled.kicad_sch]
2024-12-25 added stiching via-s and impedance controled traces for RF
    [STM32_Multimeter_PCB.kicad_pcb]
2024-12-25 created CubeIDE project, setup STM32 pins
    [STM32_Multimeter_PCB.kicad_pcb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]
2024-12-26 added i2c for oled and 2 buttons to pcb
    [STM32_Multimeter_PCB.kicad_pcb, STM32_Multimeter_PCB.kicad_sch]
2024-12-26 added pin names to silkscreen
    [STM32_Multimeter_PCB.kicad_pcb]
2024-12-29 added TIM2 input capture for measuring frequency of the LC circuit
2025-01-02 added PCB 3D model img files
2025-01-02 added masurment controll state machine and button interrupts
2025-01-12 added missing shop links to the part list
    [STM32_Multimeter_PCB.csv, STM32_Multimeter_PCB.kicad_pcb, STM32_Multimeter_PCB.kicad_sch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]

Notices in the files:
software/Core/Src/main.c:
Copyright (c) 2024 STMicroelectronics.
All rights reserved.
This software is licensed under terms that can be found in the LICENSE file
